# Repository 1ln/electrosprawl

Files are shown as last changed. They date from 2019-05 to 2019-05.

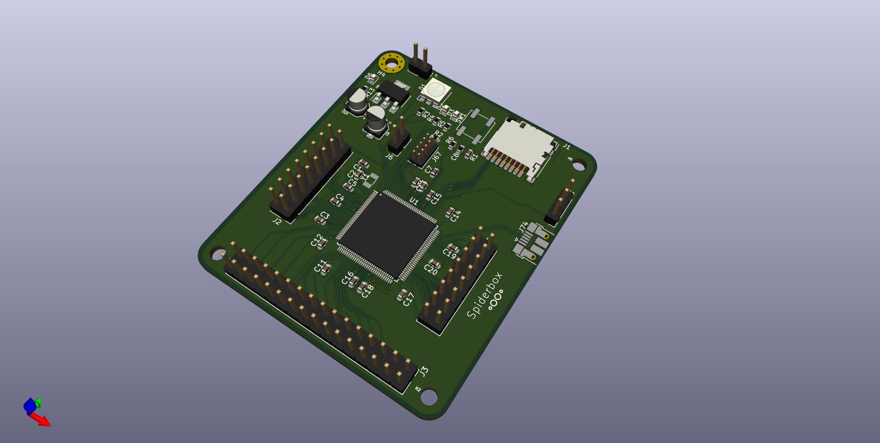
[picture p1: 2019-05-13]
electrosprawl.png

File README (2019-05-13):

Electrosprawl pcb

Hardware Design: 

Dan Olson 
Copyright 2019

This board is currently is testing phase, use at your own risk.

This board is designed as a testing platform for the cortex m4 samd51p20

Features:

Most pins broken out
Board can be attached to a raspberry pi 3 (board only, not pin header compatible)
Micro Sdcard slot
Micro usb available, 5v only

TODO:

Break out a few more pins if possible

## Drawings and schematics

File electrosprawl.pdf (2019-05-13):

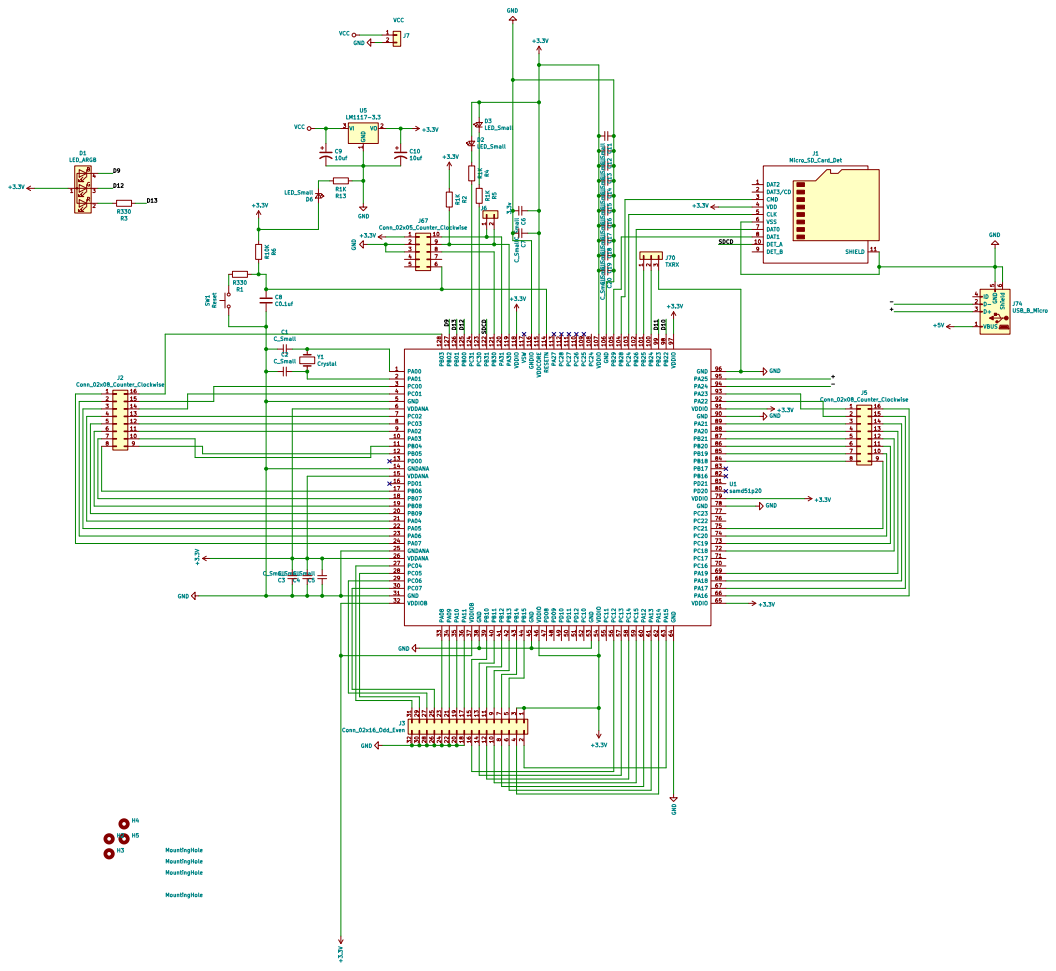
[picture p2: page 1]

2 | 15 | | 92 PA23
3 | 14 | 91 PA22 90 VDDIO

6 | 11 | 88 PA21 4 | 13
7 | 10 | 87 PA20 5 | 12

File: electrosprawl.sch Sheet: /

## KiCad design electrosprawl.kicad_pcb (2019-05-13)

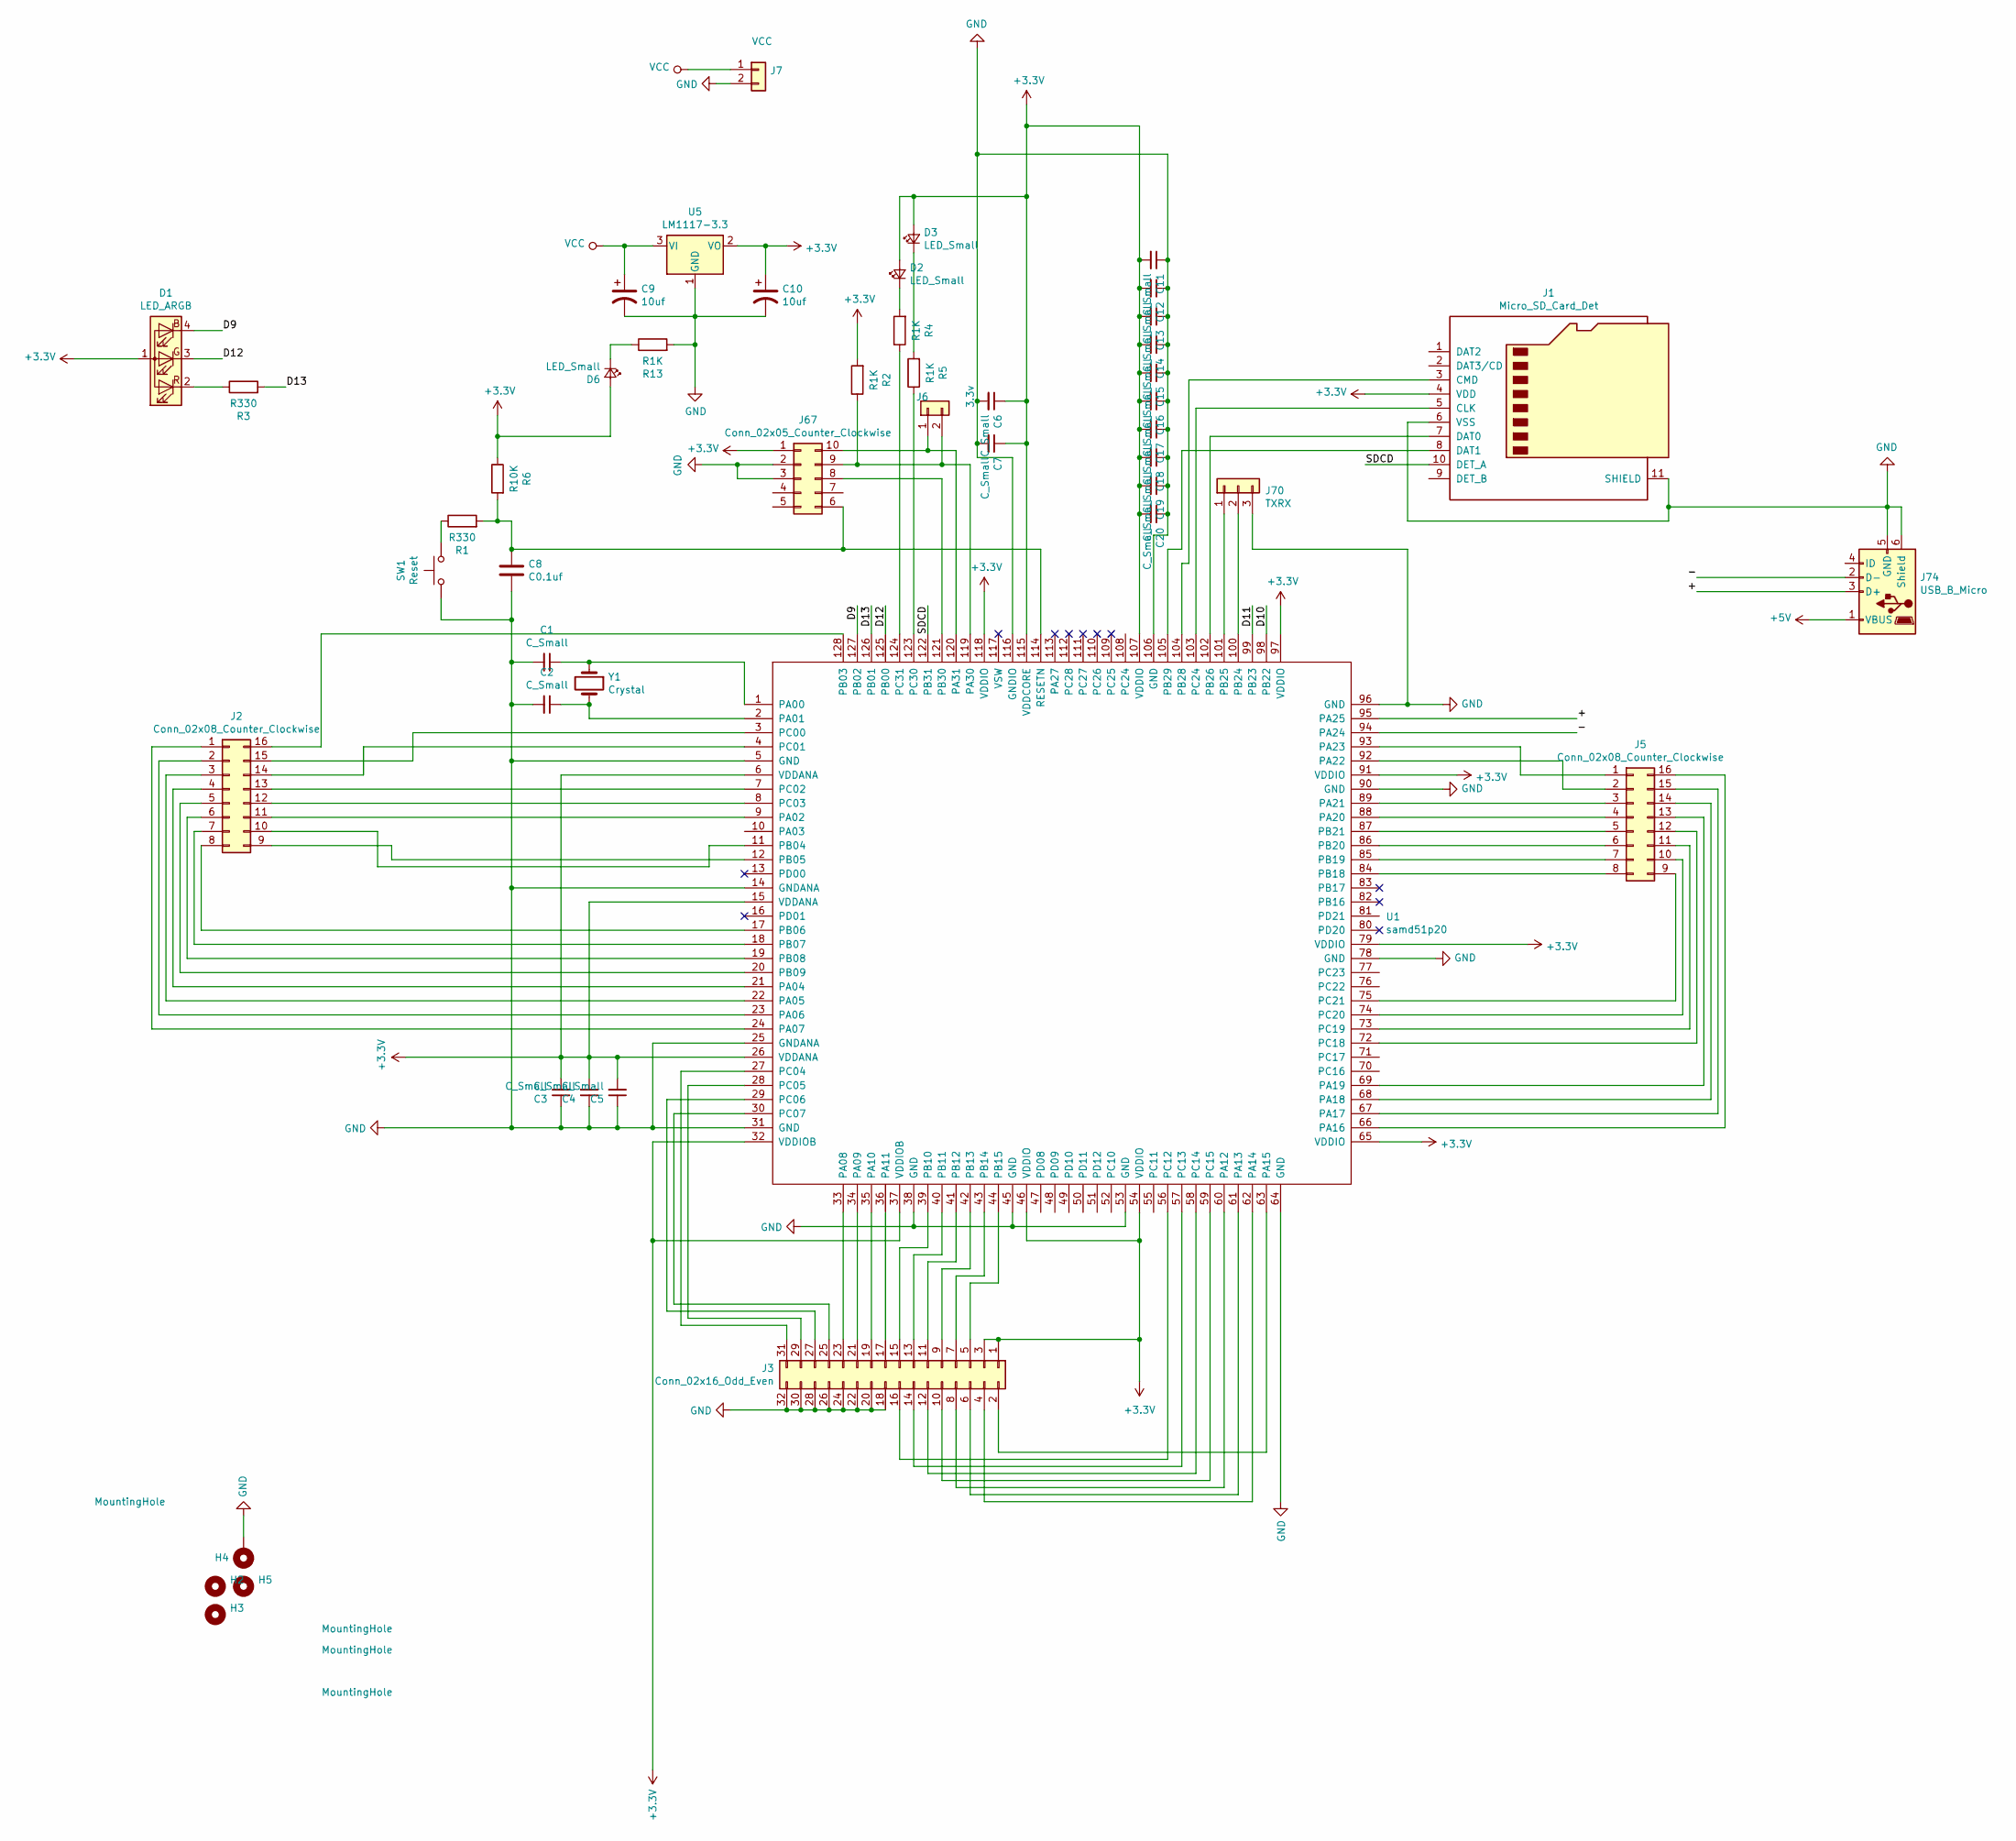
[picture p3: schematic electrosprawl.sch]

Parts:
C1, C2, C3, C4, C5, C6, C7, C11, C12, C13, C14, C15, C16, C17, C18, C19, C20: C_Small; C_0603_1608Metric
C8: C0.1uf; C_0603_1608Metric
C9: 10uf; CP_Elec_4x5.3
C10: 10uf; CP_Elec_4x4.5
D1: LED_ARGB; LED_RGB_5050-6
D2, D3, D6: LED_Small; LED_0603_1608Metric
H2, H3, H5: MountingHole; MountingHole_3mm
H4: MountingHole; MountingHole_3mm_Pad_Via
J1: Micro_SD_Card_Det; microSD_HC_Hirose_DM3D-SF
J2, J5: Conn_02x08_Counter_Clockwise; PinHeader_2x08_P2.54mm_Vertical
J3: Conn_02x16_Odd_Even; PinHeader_2x16_P2.54mm_Vertical
J6: 3.3v; PinHeader_1x02_P2.54mm_Vertical
J7: VCC; PinHeader_1x02_P2.54mm_Vertical
J67: Conn_02x05_Counter_Clockwise; PinHeader_2x05_P1.27mm_Vertical
J70: TXRX; PinHeader_1x03_P2.54mm_Vertical
J74: USB_B_Micro; USB_Micro-B_Amphenol_10103594-0001LF_Horizontal
R1, R3: R330; R_0603_1608Metric
R2, R4, R5, R13: R1K; R_0603_1608Metric
R6: R10K; R_0603_1608Metric
SW1: Reset; SW_SPST_EVPBF
U1: samd51p20; TQFP-128_14x14mm_P0.4mm
U5: LM1117-3.3; SOT-223
Y1: Crystal; Crystal_SMD_3215-2Pin_3.2x1.5mm

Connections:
+3V3: C3.2, C4.2, C5.2, C6.1, C7.1, C10.1, C11.2, C12.2, C13.2, C14.2, C15.2, C16.2, C17.2, C18.2, C19.2, C20.2, D1.1 (A), D2.2 (A), D3.2 (A), D6.2 (A), J1.4 (VDD), J3.1, J3.3, J67.1, R2.2, R6.1, U1.6 (VDDANA), U1.15 (VDDANA), U1.26 (VDDANA), U1.32 (VDDIOB), U1.37 (VDDIOB), U1.46 (VDDIO), U1.54 (VDDIO), U1.65 (VDDIO), U1.79 (VDDIO), U1.91 (VDDIO), U1.97 (VDDIO), U1.107 (VDDIO), U1.115 (VDDCORE), U1.118 (VDDIO), U5.2 (VO)
+5V: J74.1 (VBUS)
/+: J74.3 (D+), U1.95 (PA25)
/-: J74.2 (D-), U1.94 (PA24)
/D9: D1.4 (BK), U1.127 (PB02)
/D10: U1.98 (PB22)
/D11: U1.99 (PB23)
/D12: D1.3 (GK), U1.125 (PB00)
/D13: R3.2, U1.126 (PB01)
/SDCD: J1.10 (DET_A), U1.122 (PB31)
GND: C1.2, C2.2, C3.1, C4.1, C5.1, C6.2, C7.2, C8.2, C9.2, C10.2, C11.1, C12.1, C13.1, C14.1, C15.1, C16.1, C17.1, C18.1, C19.1, C20.1, H4.1, J1.6 (VSS), J1.11 (SHIELD), J3.18, J3.20, J3.22, J3.24, J3.26, J3.28, J3.30, J3.32, J7.2, J67.2, J67.3, J70.3, J74.5 (GND), J74.6 (Shield), R13.2, SW1.1, U1.5 (GND), U1.14 (GNDANA), U1.25 (GNDANA), U1.31 (GND), U1.38 (GND), U1.45 (GND), U1.53 (GND), U1.64 (GND), U1.78 (GND), U1.90 (GND), U1.96 (GND), U1.106 (GND), U1.116 (GNDIO), U5.1 (GND)
unnamed: C1.1, U1.1 (PA00), Y1.1
unnamed: C2.1, U1.2 (PA01), Y1.2
unnamed: C8.1, J67.6, R1.2, R6.2, U1.114 (RESETN)
unnamed: D1.2 (RK), R3.1
unnamed: D2.1 (K), R4.2
unnamed: D3.1 (K), R5.2
unnamed: D6.1 (K), R13.1
unnamed: J1.3 (CMD), U1.104 (PB28)
unnamed: J1.5 (CLK), U1.103 (PC24)
unnamed: J1.7 (DAT0), U1.102 (PB26)
unnamed: J1.8 (DAT1), U1.105 (PB29)
unnamed: J2.1, U1.24 (PA07)
unnamed: J2.2, U1.23 (PA06)
unnamed: J2.3, U1.22 (PA05)
unnamed: J2.4, U1.21 (PA04)
unnamed: J2.5, U1.20 (PB09)
unnamed: J2.6, U1.19 (PB08)
unnamed: J2.7, U1.18 (PB07)
unnamed: J2.8, U1.17 (PB06)
unnamed: J2.9, U1.12 (PB05)
unnamed: J2.10, U1.11 (PB04)
unnamed: J2.11, U1.9 (PA02)
unnamed: J2.12, U1.8 (PC03)
unnamed: J2.13, U1.7 (PC02)
unnamed: J2.14, U1.4 (PC01)
unnamed: J2.15, U1.3 (PC00)
unnamed: J2.16, U1.128 (PB03)
unnamed: J3.2, U1.63 (PA15)
unnamed: J3.4, U1.62 (PA14)
unnamed: J3.5, U1.44 (PB15)
unnamed: J3.6, U1.61 (PA13)
unnamed: J3.7, U1.43 (PB14)
unnamed: J3.8, U1.60 (PA12)
unnamed: J3.9, U1.42 (PB13)
unnamed: J3.10, U1.59 (PC15)
unnamed: J3.11, U1.41 (PB12)
unnamed: J3.12, U1.58 (PC14)
unnamed: J3.13, U1.40 (PB11)
unnamed: J3.14, U1.57 (PC13)
unnamed: J3.15, U1.39 (PB10)
unnamed: J3.16, U1.56 (PC12)
unnamed: J3.17, U1.36 (PA11)
unnamed: J3.19, U1.35 (PA10)
unnamed: J3.21, U1.34 (PA09)
unnamed: J3.23, U1.33 (PA08)
unnamed: J3.25, U1.30 (PC07)
unnamed: J3.27, U1.29 (PC06)
unnamed: J3.29, U1.28 (PC05)
unnamed: J3.31, U1.27 (PC04)
unnamed: J5.1, U1.93 (PA23)
unnamed: J5.2, U1.92 (PA22)
unnamed: J5.3, U1.89 (PA21)
unnamed: J5.4, U1.88 (PA20)
unnamed: J5.5, U1.87 (PB21)
unnamed: J5.6, U1.86 (PB20)
unnamed: J5.7, U1.85 (PB19)
unnamed: J5.8, U1.84 (PB18)
unnamed: J5.9, U1.75 (PC21)
unnamed: J5.10, U1.74 (PC20)
unnamed: J5.11, U1.73 (PC19)
unnamed: J5.12, U1.72 (PC18)
unnamed: J5.13, U1.69 (PA19)
unnamed: J5.14, U1.68 (PA18)
unnamed: J5.15, U1.67 (PA17)
unnamed: J5.16, U1.66 (PA16)
unnamed: J6.1, J67.10, U1.120 (PA31)
unnamed: J6.2, J67.9, R2.1, U1.119 (PA30)
unnamed: J67.8, U1.121 (PB30)
unnamed: J70.1, U1.101 (PB25)
unnamed: J70.2, U1.100 (PB24)
unnamed: R1.1, SW1.2
unnamed: R4.1, U1.124 (PC31)
unnamed: R5.1, U1.123 (PC30)
VCC: C9.1, J7.1, U5.3 (VI)

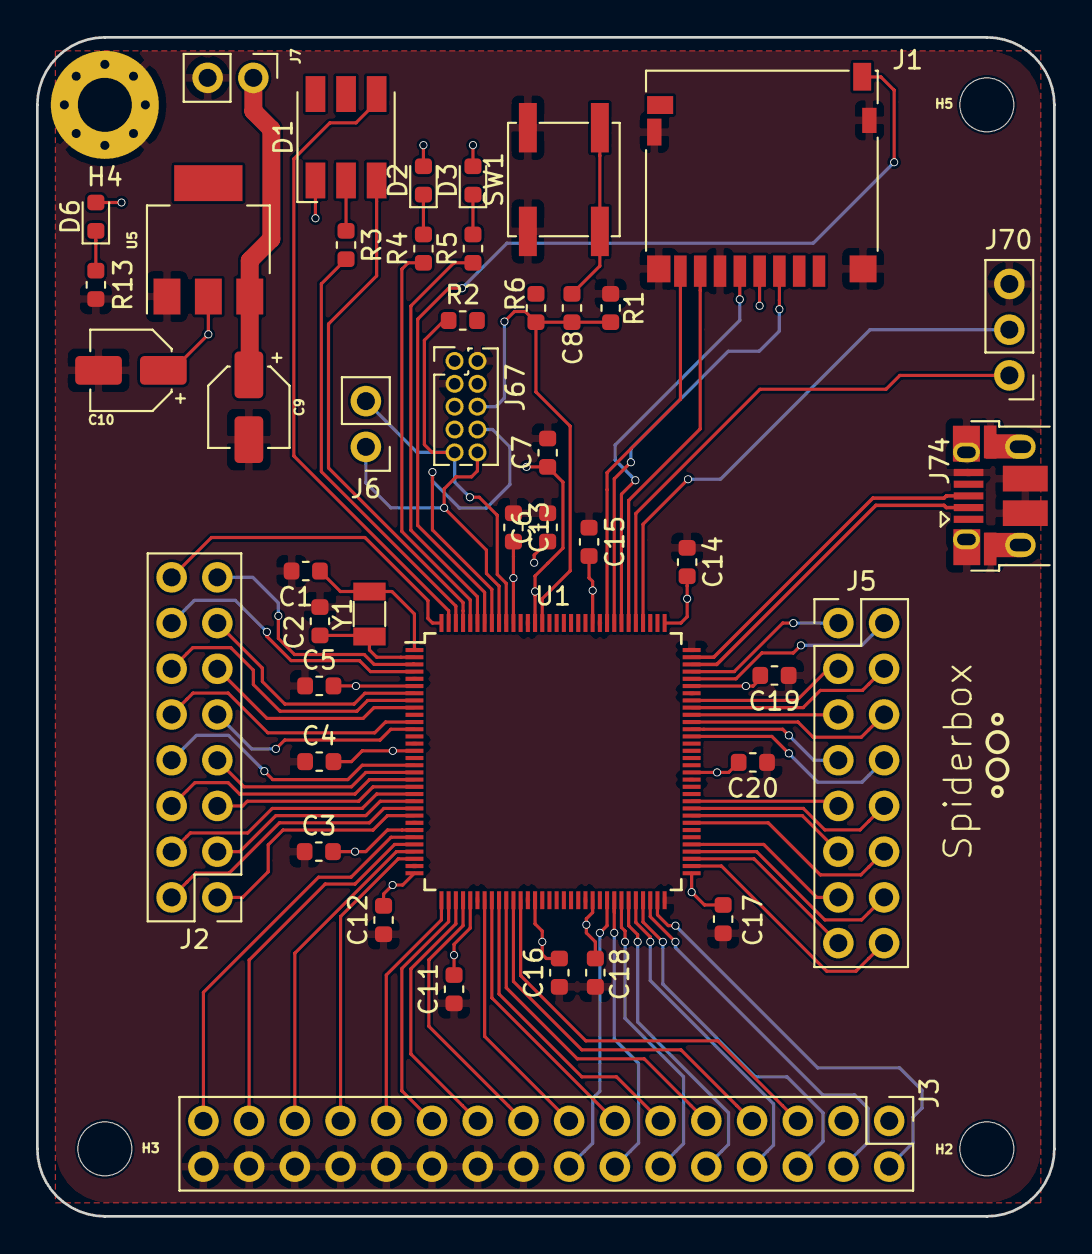
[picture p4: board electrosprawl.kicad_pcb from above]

Board: 2 copper layers, 56.5 x 65.5 mm, 48 parts (0 on the bottom side), 82 nets.

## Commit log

2019-03-29 update schematic
    [regius.sch]
2019-03-29 debug port
    [regius.kicad_pcb, regius.sch]
2019-03-30 update design
    [regius.sch]
2019-03-31 add footprints
    [regius.sch]
2019-03-31 add 3d image
    [regius.kicad_pcb, regius.sch]
2019-04-02 update schematic tca9548
    [regius.kicad_pcb, regius.sch]
2019-04-02 update layout design
    [regius.kicad_pcb, regius.sch]
2019-04-03 update layout
    [regius.kicad_pcb, regius.sch]
2019-04-06 rename project
    [electrosprawl.kicad_pcb, electrosprawl.sch]
2019-04-06 update i2c with sx1509
    [electrosprawl-B.Cu.gbl, electrosprawl-B.Mask.gbs, electrosprawl-B.Paste.gbp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]
2019-04-07 update layout redesign
    [electrosprawl.kicad_pcb, electrosprawl.sch]
2019-04-15 update redesign
    [electrosprawl.kicad_pcb, electrosprawl.sch]
2019-05-07 add rgb led
    [electrosprawl.kicad_pcb, electrosprawl.sch]
